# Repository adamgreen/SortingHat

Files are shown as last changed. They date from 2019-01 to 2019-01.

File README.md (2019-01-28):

# BLE Harry Potter Sorting Hat
This project replaces the original electronics in a [Harry Potter Sorting Hat](https://www.barnesandnoble.com/w/home-gift-harry-potter-sorting-hat/30008992) with a Nordic nRF5 BLE capable device.

## Legal Notes
* This Harry Potter Sorting Hat upgrade is created by a Harry Potter fan for other such fans. It is not sponsored or endorsed by Warner Bros. Entertainment or J.K. Rowling.
* Materials from the Harry Potter series of films are the intellectual property of Warner Bros. Entertainment.

## Project Overview
The user can connect to the device with a BLE capable phone using the Nordic UART service and send **g**, **r**, **h**, or **s** to select the house and then a series of random clips from the movies will play, ending with an announcement of the selected house.

The sound clips are stored on SD card as .wav files and are played back by pulsing a pin as a 1-bit DAC at 22.05kHz. The mouth is connected to a hobby servo instead of the original open-loop DC motor and the position of this servo is based on the volume in upcoming audio buffers.

## Credits
The sound clips and the code flow to randomly select between them originates from the https://github.com/gowenrw/arduino_sorting_hat repository created by [@gowenrw](https://github.com/gowenrw).

This sample is heavily influenced by Nordic's BLE UART Service (ble_app_uart) SDK sample.

## Firmware Build
I have only tested the build on macOS but it might work on other Posix operating systems too.

**Note:** Building the firmware and deploying it to the nRF51 requires the **nrfjprog** tool. The archive for your OS can be downloaded from [here](https://www.nordicsemi.com/Software-and-Tools/Development-Tools/nRF5-Command-Line-Tools). You will also need a SEGGER J-Link JTAG/SWD Debugger. If your projects are of a non-commercial nature, you can use this [low cost module available from Adafruit](https://www.adafruit.com/product/3571).

* `make sdk` will download and install the required Nordic SDK. This should only need to be done once.
* `make audio` will generate the .wav files to be placed in the root folder of the SD card.
* `make flash_softdevice` will install the required Nordic SoftDevice on the nRF51422 microcontroller using the J-Link debugger. This will typically only need to be done once for each microcontroller.
* `make all` will build the hat firmware.
* `make flash` will build the hat firmware and deploy it using the J-Link debugger.

# Bill of Materials
Description | Quantity | Part Number(s)
------------|----------|---------------
[LM386MMX-1 Low Voltage Audio Amplifier](https://www.digikey.com/products/en?keywords=LM386MMX-1/NOPBCT-ND) | 1 | IC1
[MIC5205 Linear Regulator - 3.3V 150mA SOT23-5](https://www.digikey.com/products/en?keywords=576-1259-1-ND) | 1 | U1
[microSD Socket](https://www.sparkfun.com/products/127) | 1 | JP1
[Dynastream N5150M5CD - nRF51422 Module](https://www.digikey.com/products/en?keywords=N5150M5CD) | 1 | U2
[0.01uF Capacitor - 0805](https://www.adafruit.com/product/441) | 1 | C5
[0.1uF Capacitor - 0805](https://www.adafruit.com/product/441) | 4 | C3, C4, C8, C10
[10uF Capacitor (16V) - Tantalum](https://www.digikey.com/products/en?keywords=478-8235-1-ND) | 4 | C1, C2, C6, C7
[220uF Capacitor (10V) - Tantalum](https://www.digikey.com/products/en?keywords=478-6612-1-ND) | 1 | C9
[10kΩ Resistor - 0805](https://www.adafruit.com/product/441) | 1 | R1
[10Ω Resistor - 0805](https://www.adafruit.com/product/441) | 1 | R6
[1kΩ Resistor - 0805](https://www.adafruit.com/product/441) | 3 | R2, R3, R7
[4.7kΩ Resistor - 0805](https://www.adafruit.com/product/441) | 1 | R4
[10kΩ 11-TurnTrimmer Potentiometer](https://www.digikey.com/products/en?keywords=3223W-1-103ECT-ND) | 1 | R5
[Sliding Switch](https://www.digikey.com/products/en?keywords=EG2481-ND) | 1 | S1

# Schematic
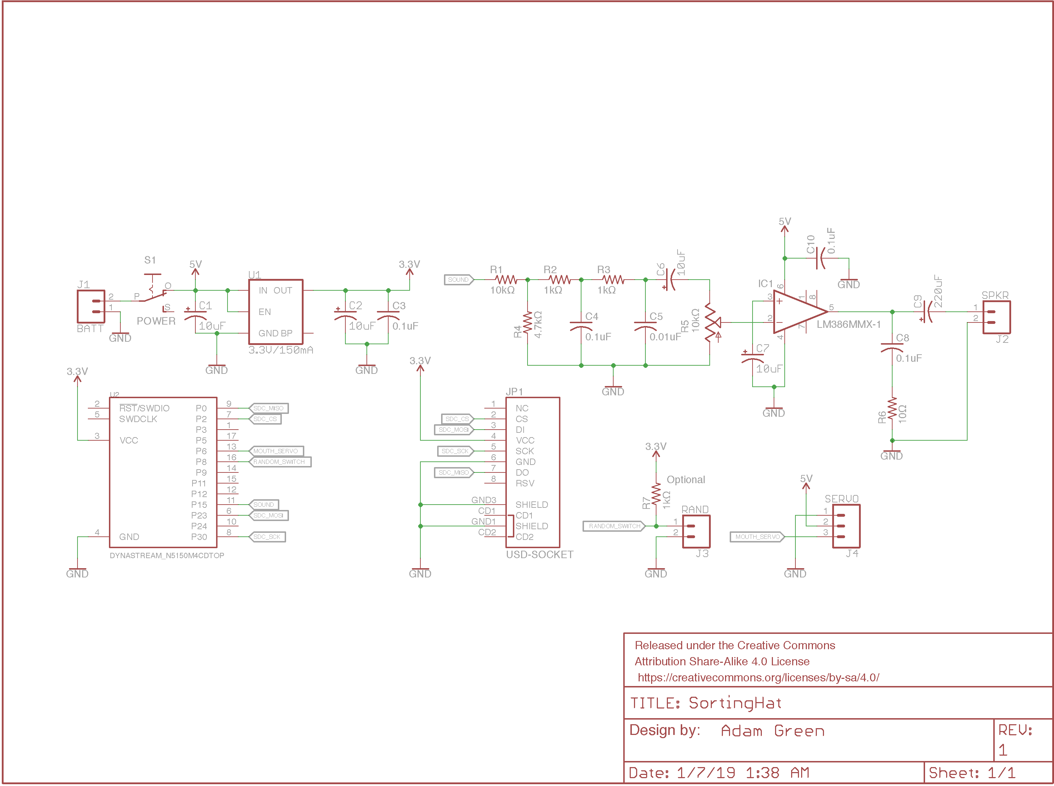
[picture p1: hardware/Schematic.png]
Schematic


# OSHPark Renderings of PCB
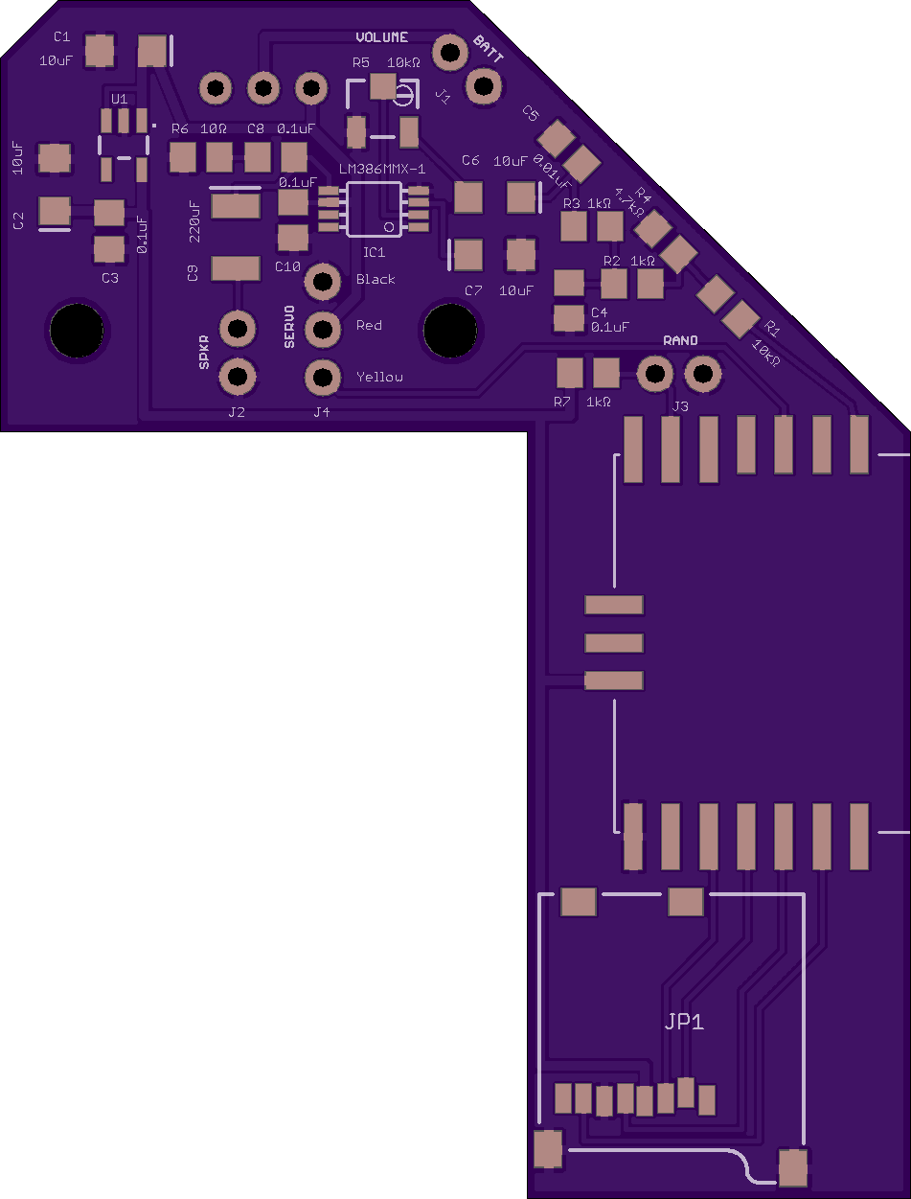
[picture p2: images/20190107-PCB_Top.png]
OSHPark rendering of PCB Top

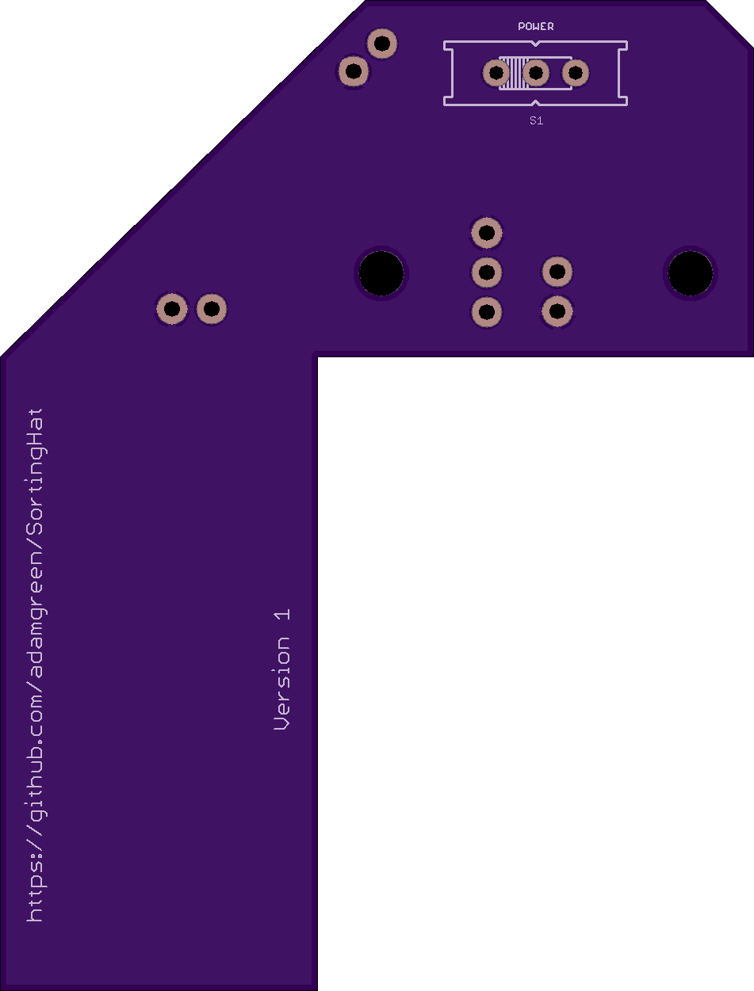
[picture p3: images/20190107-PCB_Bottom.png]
OSHPark rendering of PCB Bottom


# Postmortem
Things that worked well in the current prototype version of this sorting hat as documented here:
* Getting the house selection via BLE from a custom iOS application.
* Changing out the reciprocating mouth mechanism to instead use a servo with a push-rod mechanism. 
* Reading in the .wav files from uSD card.
* Continuing to support the original button on the hat brim for random house selection.

Things that didn't work as well as I had hoped:
* The LM386 as seen in the above schematic was very sensitive to noise in the 5V supply caused by the servo so I ended up removing it and just using a NPN BJT as described [here](https://makezine.com/projects/make-35/advanced-arduino-sound-synthesis/).
* The audio quality was quite low. There was a hum in the audio. Seems like it might have been from noise on the nRF51 sound output pin when it is in the high state.
* While the LM386 volume level was Ok, once I switched it out for a single NPN transistor, the volume level was quite low.
* The PCB should be modified to better fit inside the hat:
  * It is currently too wide at the bottom, to the right of the uSD card reader and I had to file it down. I should have cut the bottom in like the top and put the SD card reader there pointed inwards (to the left). 
  * The power connector is hard to get to since it is right underneath the speaker.
  * I forgot to label the pins for the BATT header.
  * The antenna of the nRF51 module is a bit tight against the side of the hat. Could have narrowed the PCB width down a bit and pulled module to the left a mm or so.
  * The R5 potentiometer was way too close to back edge and actually got bent up by speaker holder.
  * The C1 capacitor should be moved down a bit as it currently hits up against the bottom of the speaker holder.
  
Things I would change if I ever come back to this project to build a newer prototype version:
* Update the PCB to fix the issues mentioned above.
* Switch to using a nRF52 based microcontroller instead. This chip supports DMA based PWM and I2S.
* Use a I2S based amplified DAC such as the [MAX98357A](https://www.adafruit.com/product/3006) to replace the 1-bit DAC and LM386 in the current project. This would probably allow the BLE connection to be maintained while the house announcement was in progress and greatly improve the sound quality.

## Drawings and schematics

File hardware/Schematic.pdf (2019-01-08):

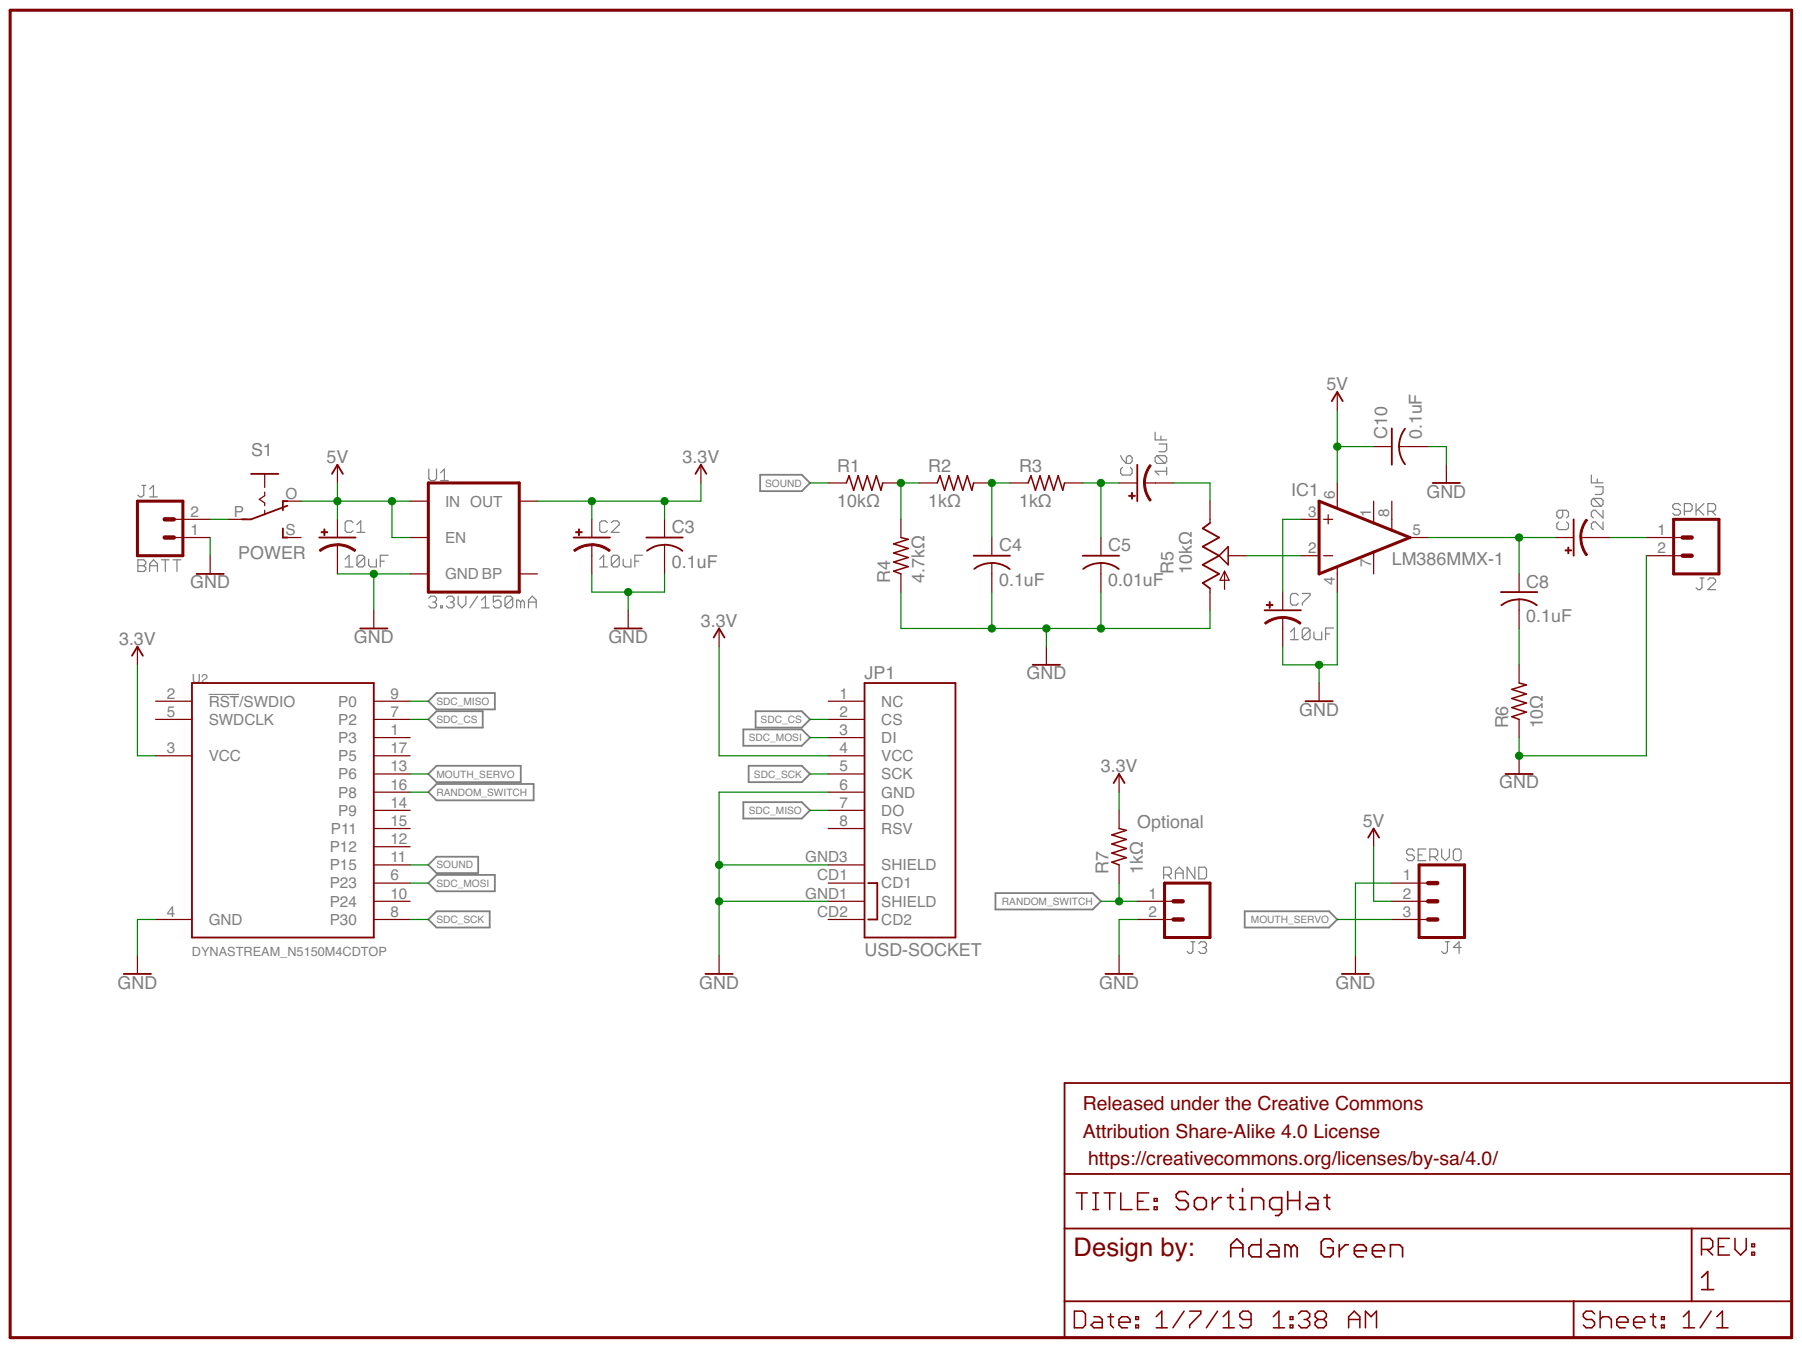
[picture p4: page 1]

Released under the Creative Commons Attribution Share-Alike 4.0 License

https://creativecommons.org/licenses/by-sa/4.0/

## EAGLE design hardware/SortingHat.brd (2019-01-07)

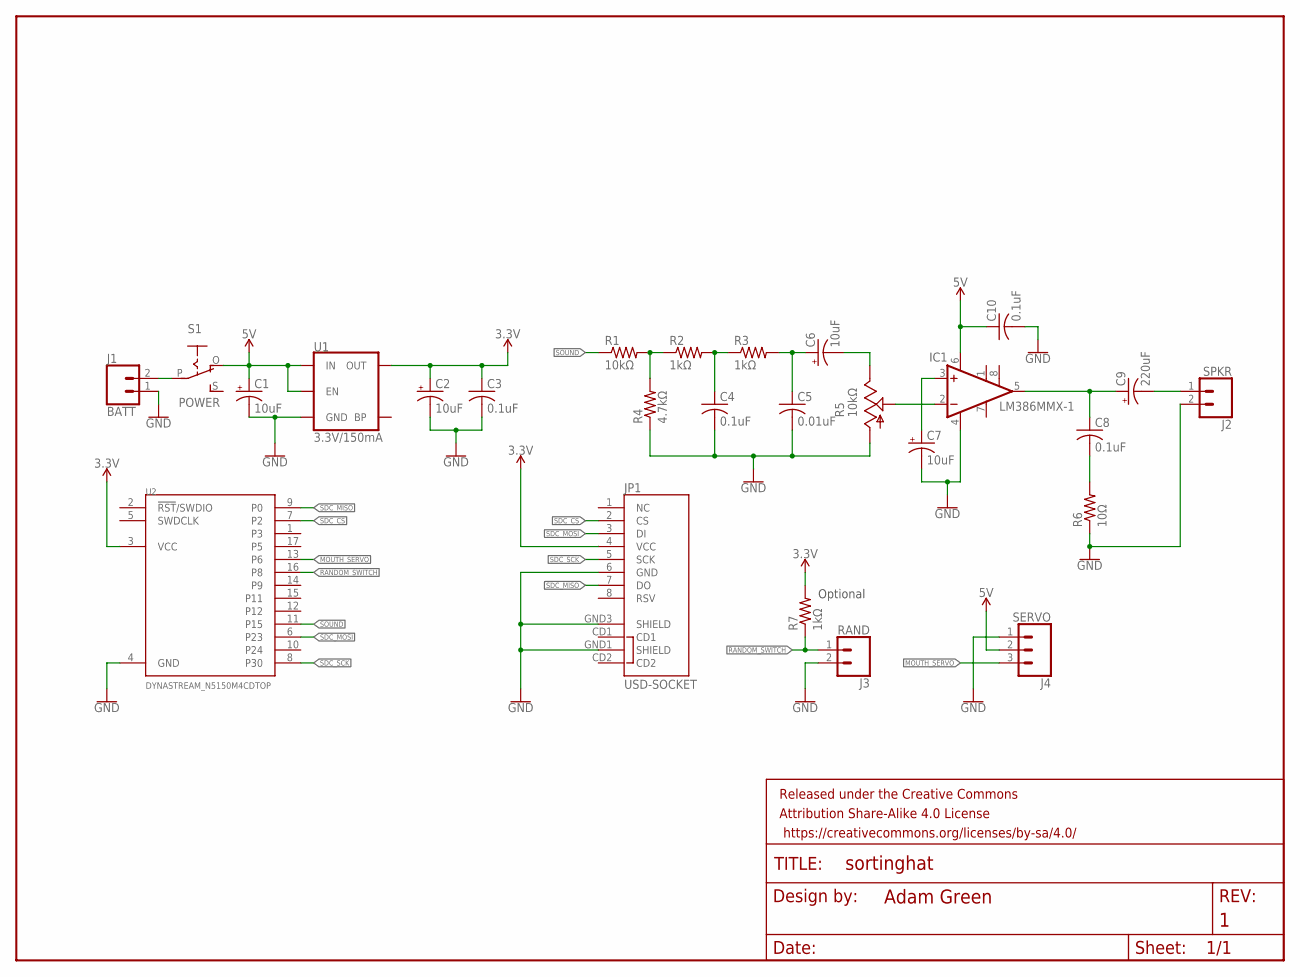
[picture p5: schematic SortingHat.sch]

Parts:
C1, C2, C6, C7: 10uF; EIA3216
C3, C4, C8, C10: 0.1uF; C0805
C5: 0.01uF; C0805
C9: 220uF; EIA3528
FRAME1: FRAME-LETTER; CREATIVE_COMMONS
IC1: LM386MMX-1; MMSOP08
J1: BATT; 1X02_NO_SILK
J2: SPKR; 1X02_NO_SILK
J3: RAND; 1X02_NO_SILK
J4: SERVO; 1X03_NO_SILK
JP1: USD-SOCKET; MICROSD_1:1
R1: 10kΩ; R0805
R2, R3, R7: 1kΩ; R0805
R4: 4.7kΩ; R0805
R5: 10kΩ; 3223W
R6: 10Ω; R0805
S1: POWER; EG1218
U1: 3.3V/150mA; SOT23-5
U2: DYNASTREAM_N5150M4CDTOP; N5150M4CD_TOP

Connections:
3.3V: C2.+, C3.1, JP1.4 (VCC), R7.2, U1.5 (OUT), U2.3 (VCC)
5V: C1.+, C10.1, IC1.6 (VS), J4.2, S1.O, U1.1 (IN), U1.3 (EN)
GND: C1.-, C2.-, C3.2, C4.2, C5.2, C7.-, C10.2, IC1.4 (GND), J1.1, J2.2, J3.2, J4.1, JP1.6 (GND), JP1.GND1 (SHIELD), JP1.GND3 (SHIELD), R4.1, R5.1 (A), R6.1, U1.2 (GND), U2.4 (GND)
MOUTH_SERVO: J4.3, U2.13 (P6)
unnamed: J1.2, S1.P
unnamed: R1.2, R2.1, R4.2
unnamed: C4.1, R2.2, R3.1
unnamed: C5.1, C6.+, R3.2
unnamed: C6.-, R5.3 (E)
unnamed: C9.C (-), J2.1
unnamed: IC1.2 (-IN), R5.2 (S)
unnamed: C7.+, IC1.3 (+IN)
unnamed: C8.1, C9.A (+), IC1.5 (OUT)
unnamed: C8.2, R6.2
RANDOM_SWITCH: J3.1, R7.1, U2.16 (P8)
SDC_CS: JP1.2 (CS), U2.7 (P2)
SDC_MISO: JP1.7 (DO), U2.9 (P0)
SDC_MOSI: JP1.3 (DI), U2.6 (P23)
SDC_SCK: JP1.5 (SCK), U2.8 (P30)
SOUND: R1.1, U2.11 (P15)

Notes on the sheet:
Optional

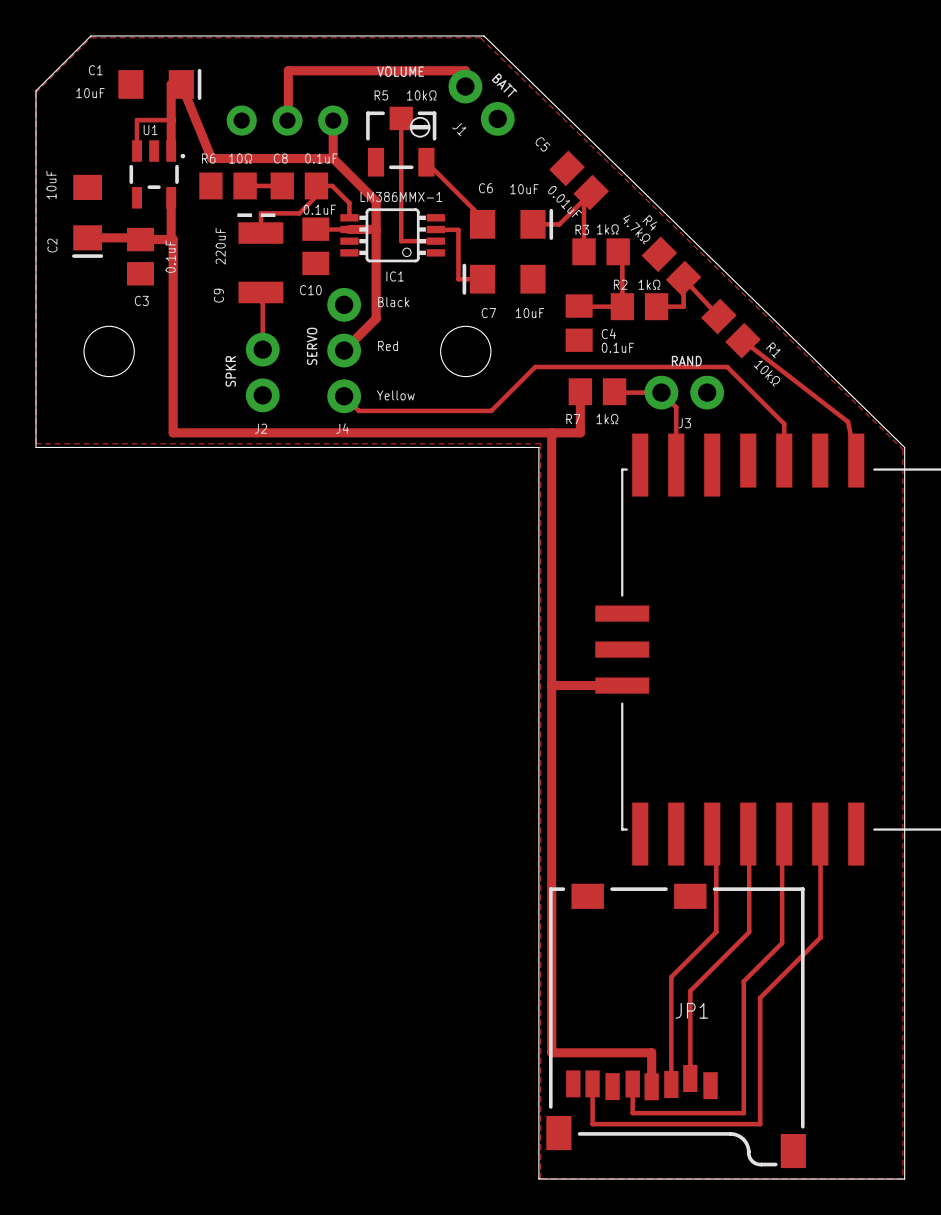
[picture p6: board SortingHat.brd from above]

Board: 2 copper layers, 48.3 x 63.5 mm, 27 parts (1 on the bottom side), 20 nets.

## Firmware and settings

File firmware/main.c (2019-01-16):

/*  Copyright (C) 2019  Adam Green (https://github.com/adamgreen)

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
    This program is distributed in the hope that it will be useful,
    but WITHOUT ANY WARRANTY; without even the implied warranty of
    MERCHANTABILITY or FITNESS FOR A PARTICULAR PURPOSE.  See the
    GNU General Public License for more details.
*/
/* A Bluetooth Low Energy (BLE) enabled Harry Potter Sorting Hat

   This project replaces the original electronics in the Harry Potter Sorting Hat from Barnes and Noble,
   https://www.barnesandnoble.com/w/home-gift-harry-potter-sorting-hat/30008992, with a Nordic nRF5 BLE capable device.

   Pins.h contains the definitions for which pins are connected to which external hardware.

   The user can connect to the device with a BLE capable phone using the Nordic UART service and send 'g', 'r', 'h', or
   's' to select the house and then a series of random clips from the movies will play, ending with an announcement of
   the selected house.

   The sound clips are stored on SD card as .wav files and are played back by pulsing a pin as a 1-bit DAC at 22.05kHz.
   The mouth is connected to a hobby servo instead of the original open-loop DC motor and the position of this servo
   is based on the volume in upcoming audio buffers.

   The sound clips and the code flow to randomly select between them originates from
   https://github.com/gowenrw/arduino_sorting_hat created by @gowenrw, Richard Gowen.

   This sample is heavily influenced by Nordic's BLE UART Service (ble_app_uart) SDK sample.
*/
#include <ctype.h>
#include <math.h>
#include <stdint.h>
#include <string.h>
#include <app_button.h>
#include <app_pwm.h>
#include <app_timer.h>
#include <app_uart.h>
#include <ble_advdata.h>
#include <ble_advertising.h>
#include <ble_conn_params.h>
#include <ble_hci.h>
#include <ble_nus.h>
#include <nordic_common.h>
#include <nrf.h>
#include <nrf_drv_gpiote.h>
#include <nrf_drv_rng.h>
#include <softdevice_handler.h>
#include "WaveFile.h"
#include "OneBitSound.h"
#include "Pins.h"



// The service database for this device can't be changed at runtime. Must be non-zero for DFU.
#define IS_SRVC_CHANGED_CHARACT_PRESENT 0

#if (NRF_SD_BLE_API_VERSION == 3)
// MTU size used in the softdevice enabling and to reply to a BLE_GATTS_EVT_EXCHANGE_MTU_REQUEST event.
#define NRF_BLE_MAX_MTU_SIZE            GATT_MTU_SIZE_DEFAULT
#endif

// Reply when unsupported features are requested.
#define APP_FEATURE_NOT_SUPPORTED       BLE_GATT_STATUS_ATTERR_APP_BEGIN + 2

// This application doesn't need to act as a central device.
#define CENTRAL_LINK_COUNT              0
// This application is a peripheral and only hosts 1 peripheral link back to a central device.
#define PERIPHERAL_LINK_COUNT           1

#define DEVICE_NAME                     "SortingHat"

// UUID type for the Nordic UART Service (vendor specific).
#define NUS_SERVICE_UUID_TYPE           BLE_UUID_TYPE_VENDOR_BEGIN

// The advertising interval (in units of 0.625 ms. This value corresponds to 40 ms).
#define APP_ADV_INTERVAL                64
// The advertising timeout (in units of seconds).
#define APP_ADV_TIMEOUT_IN_SECONDS      180

// Value of the RTC1 PRESCALER register.
#define APP_TIMER_PRESCALER             0
// Size of timer operation queues.
#define APP_TIMER_OP_QUEUE_SIZE         4

// Timings for how often peripheral and central should communicate over the link. The shorter the interval, the more
// data that can be sent over the link but uses more CPU and power resources.
// Minimum acceptable connection interval (20 ms), Connection interval uses 1.25 ms units.
#define MIN_CONN_INTERVAL               MSEC_TO_UNITS(20, UNIT_1_25_MS)
// Maximum acceptable connection interval (75 ms), Connection interval uses 1.25 ms units.
#define MAX_CONN_INTERVAL               MSEC_TO_UNITS(75, UNIT_1_25_MS)
// The number of the connection interval events that the peripheral can ignore before response is required.
#define SLAVE_LATENCY                   0

// Connection supervisory timeout (4 seconds), Supervision Timeout uses 10 ms units.
#define CONN_SUP_TIMEOUT                MSEC_TO_UNITS(4000, UNIT_10_MS)
// Time from initiating event (connect or start of notification) to first time sd_ble_gap_conn_param_update is called (5 seconds).
#define FIRST_CONN_PARAMS_UPDATE_DELAY  APP_TIMER_TICKS(5000, APP_TIMER_PRESCALER)
// Time between each call to sd_ble_gap_conn_param_update after the first call (30 seconds).
#define NEXT_CONN_PARAMS_UPDATE_DELAY   APP_TIMER_TICKS(30000, APP_TIMER_PRESCALER)
// Number of attempts before giving up the connection parameter negotiation.
#define MAX_CONN_PARAMS_UPDATE_COUNT    3

#define UART_TX_BUF_SIZE                256
#define UART_RX_BUF_SIZE                256



static ble_nus_t                    g_nordicUartService;
static uint16_t                     g_currBleConnection = BLE_CONN_HANDLE_INVALID;

// UUIDS returned in advertising scan response.
static ble_uuid_t                   g_advertiseUuids[] = {{BLE_UUID_NUS_SERVICE, NUS_SERVICE_UUID_TYPE}};

// Where the main thread should write the next entry in OneBitSound's g_soundBuffers array.
static          size_t              g_soundBufferWrite = 0;

// The number of buffers that have been filled with descending values to ramp down the voltage to the amplifier input.
static          uint32_t            g_soundFinalBuffers = 0;

// The list of wave files to play.
static          const char*         g_wavesToPlay[6];
static          const char**        g_ppCurrentWave = &g_wavesToPlay[5];

// The .wav file handle currently being read for playback.
static          FIL                 g_wavFile;

// PWM instance for servo control uses TIMER2.
APP_PWM_INSTANCE(PWM1, 2);

// The number of clock ticks for mouth fully open and closed position of servo.
static          int32_t             g_closedMouthClockTicks;
static          int32_t             g_openMouthClickTicks;
static          int32_t             g_mouthClockTickRange;



// Forward Function Declarations.
static void pullSoundAndServoOutputPinsLow();
static void initUart(void);
static void uartEventHandler(app_uart_evt_t* pEvent);
static void playHouseAnnouncement(uint8_t houseSelection);
static void soundBufferRead(void* pEventData, uint16_t eventSize);
static void  fillFinalSoundBuffers();
static int32_t calculateMaxVolume(uint8_t* pData, size_t length);
static void enterLowPowerModeUntilNextScheduledEvent();
static void waitForBleHouseChoice();
static void initRandomSwitch();
static void randomSelectionSwitchPressedHandler(nrf_drv_gpiote_pin_t pin, nrf_gpiote_polarity_t action);
static void initBleStack(void);
static void bleEventHandler(ble_evt_t* pBleEvent);
static void handleBleEventsForApplication(ble_evt_t* pBleEvent);
static void initGapParams(void);
static void initBleUartService(void);
static void nordicUartServiceHandler(ble_nus_t* pNordicUartService, uint8_t* pData, uint16_t length);
static void initBleAdvertising(void);
static void bleAdvertisingEventHandler(ble_adv_evt_t bleAdvertisingEvent);
static void enterDeepSleep(void);
static void initConnectionParameters(void);
static void connectionParameterEventHandler(ble_conn_params_evt_t* pEvent);
static void connectionParameterErrorHandler(uint32_t errorCode);
static void enterLowPowerModeUntilNextEvent(void);



int main(void)
{
    pullSoundAndServoOutputPinsLow();

    initUart();
    printf("\nHarry Potter Sorting Hat Hack!\n");

    // If the user selected a house via a BLE connection, the selection will have been placed in GPREGRET and then the
    // device reset.
    uint8_t houseSelection = NRF_POWER->GPREGRET;
    NRF_POWER->GPREGRET = 0;
    if (houseSelection != 0)
    {
        playHouseAnnouncement(houseSelection);
    }
    else
    {
        waitForBleHouseChoice();
    }

    return -1;
}

static void pullSoundAndServoOutputPinsLow()
{
    nrf_gpio_cfg_output(SOUND_PIN);
    nrf_gpio_pin_clear(SOUND_PIN);
    nrf_gpio_cfg_output(MOUTH_SERVO_PIN);
    nrf_gpio_pin_clear(MOUTH_SERVO_PIN);
}

static void initUart(void)
{
    uint32_t                     errorCode;
    const app_uart_comm_params_t commParams =
    {
        UART_RX_PIN,
        UART_TX_PIN,
        0xFF, // RTS not used
        0xFF, // CTS not used
        APP_UART_FLOW_CONTROL_DISABLED,
        false,
        UART_BAUDRATE_BAUDRATE_Baud115200
    };

    APP_UART_FIFO_INIT(&commParams,
                       UART_RX_BUF_SIZE,
                       UART_TX_BUF_SIZE,
                       uartEventHandler,
                       APP_IRQ_PRIORITY_LOWEST,
                       errorCode);
    APP_ERROR_CHECK(errorCode);
}

static void uartEventHandler(app_uart_evt_t * pEvent)
{
    uint8_t     dummyByte;

    switch (pEvent->evt_type)
    {
        case APP_UART_DATA_READY:
            // Just eat and discard any received UART bytes at this time.
            app_uart_get(&dummyByte);
            break;

        case APP_UART_COMMUNICATION_ERROR:
            APP_ERROR_HANDLER(pEvent->data.error_communication);
            break;

        case APP_UART_FIFO_ERROR:
            APP_ERROR_HANDLER(pEvent->data.error_code);
            break;

        default:
            break;
    }
}

// The sound clips and the code flow to randomly select between them originates from
// https://github.com/gowenrw/arduino_sorting_hat created by Richard Gowen (@alt_bier)
static void playHouseAnnouncement(uint8_t houseSelection)
{
    uint32_t errorCode;

    printf("Playing house announcement...\n");

    APP_SCHED_INIT(0, 2);

    // Initialize the PWM instance used for the servo control of the hat's mouth.
    app_pwm_config_t pwm1_cfg = APP_PWM_DEFAULT_CONFIG_1CH(1000000/50, MOUTH_SERVO_PIN);
    pwm1_cfg.pin_polarity[0] = APP_PWM_POLARITY_ACTIVE_HIGH;

    // Initialize and enable PWM for the servo.
    errorCode = app_pwm_init(&PWM1, &pwm1_cfg, NULL);
    APP_ERROR_CHECK(errorCode);
    app_pwm_enable(&PWM1);

    // Determine the number of clock ticks for mouth fully closed and mouth fully opened.
    float ticksPerMillisecond = (float)app_pwm_cycle_ticks_get(&PWM1) / 20.0f;
    g_closedMouthClockTicks = ticksPerMillisecond * 1.75f;
    g_mouthClockTickRange = ticksPerMillisecond * -0.4f;
    g_openMouthClickTicks = g_closedMouthClockTicks + g_mouthClockTickRange;
    // Amplify the mouth movement a bit.
    g_mouthClockTickRange *= 1.5;

    fatfsInit();

    const char* pHouseClip;
    switch (houseSelection)
    {
    case 'g':
        pHouseClip = "h-gryff1.wav";
        break;
    case 'r':
        pHouseClip = "h-raven1.wav";
        break;
    case 'h':
        pHouseClip = "h-huffl1.wav";
        break;
    case 's':
        pHouseClip = "h-slyth1.wav";
        break;
    default:
        return;
    }

    // Setup Audio File Name Arrays
    // Array of Stalling Audio Clips
    static const char* stallingClips[] =
    {
        "s-ahrigh.wav", // "Ahh... Right then."
        "s-diffic.wav", // "Hmm... Difficult, very difficult."
        "s-itsall.wav", // "You could be great, you know.  It's all here, in your head." -- break into two clips put great to attributes
        "s-ohyes1.wav", // "Oh, Yes."
        "s-righto.wav", // "Hm, right. Ok."
        "s-wheret.wav"  // "But where to put you?"
    };
    // Array of Attribute Audio Clips
    static const char* attributeClips[] =
    {
        "t-courag.wav", // "Plenty of courage, I see."
        "t-notaba.wav", // "Not a bad mind a..." -- needs work, either clip or expand or replace with great clip above
        "t-readym.wav", // "Ahhh yes. A ready mind."
        "t-talent.wav"  // "There's talent."
    };
    // Array of Audio Clips to play just before announcing house.
    static const char* penultimateClips[] =
    {
        "k-better.wav", // "Better be..."
        "k-iknow1.wav", // "I Know!"
        "k-iknowj.wav", // "I know just what to do with you."
        "k-youbel.wav"  // "You belong in..."
    };

    // Using the hardware random number generator since it exists and hard to get unique random selections across
    // CPU resets otherwise.
    uint8_t randNumbers[4];
    uint8_t availableBytes = 0;
    errorCode = nrf_drv_rng_init(NULL);
    APP_ERROR_CHECK(errorCode);
    do
    {
        nrf_drv_rng_bytes_available(&availableBytes);
    } while (availableBytes < sizeof(randNumbers));
    errorCode = nrf_drv_rng_rand(randNumbers, sizeof(randNumbers));
    APP_ERROR_CHECK(errorCode);

    // Determine random audio clip numbers to be played.
    int stallClip1 = randNumbers[0] % ARRAY_SIZE(stallingClips);
    int stallClip2 = (stallClip1 + 1 + (randNumbers[1] % (ARRAY_SIZE(stallingClips)-1))) % ARRAY_SIZE(stallingClips);
    int attributeClip = randNumbers[2] % ARRAY_SIZE(attributeClips);
    int penultimateClip = randNumbers[3] % ARRAY_SIZE(penultimateClips);

    // UNDONE: Remove in final version.
    if (stallClip1 == stallClip2)
    {
        // If my math above is correct then stall clip #1 should never be the same as stall clip #2.
        { __asm volatile ("bkpt #0"); }
    }

    // Queue them up for playback.
    g_wavesToPlay[0] = stallingClips[stallClip1];
    g_wavesToPlay[1] = attributeClips[attributeClip];
    g_wavesToPlay[2] = stallingClips[stallClip2];
    g_wavesToPlay[3] = penultimateClips[penultimateClip];
    g_wavesToPlay[4] = pHouseClip;
    g_wavesToPlay[5] = NULL;
    g_ppCurrentWave = &g_wavesToPlay[0];

    // Call soundBufferRead() synchronously to pre-fill the sound buffers with samples from the .wav files before
    // calling soundInit() to start the audio playback process.
    emptySoundBuffers();
    soundBufferRead(NULL, 0);

    // Start the timer interrupt used for audio playback.
    errorCode = soundInit(SOUND_PIN, soundBufferRead);
    APP_ERROR_CHECK(errorCode);

    for (;;)
    {
        enterLowPowerModeUntilNextScheduledEvent();
    }
}

// Fills in sound buffers with samples from the list of SD card based .wav audio files.
static void soundBufferRead(void * pEventData, uint16_t eventSize)
{
    if (*g_ppCurrentWave == NULL)
    {
        fillFinalSoundBuffers();
        return;
    }
    if (g_wavFile.obj.fs != 0 && f_eof(&g_wavFile))
    {
        f_close(&g_wavFile);
        g_ppCurrentWave++;
    }

    // Using a while to skip over any files that fail to open.
    while (*g_ppCurrentWave && g_wavFile.obj.fs == 0)
    {
        FRESULT result = openWavFile(*g_ppCurrentWave, &g_wavFile);
        if (result != FR_OK)
        {
            f_close(&g_wavFile);
            g_ppCurrentWave++;
        }
    }
    if (g_wavFile.obj.fs == 0)
    {
        fillFinalSoundBuffers();
        return;
    }

    // Fill in as many of the buffer as possible.
    for (size_t i = 0 ; i < ARRAY_SIZE(g_soundBuffers) ; i++)
    {
        SoundBuffer* pBuffer = &g_soundBuffers[g_soundBufferWrite];
        if (pBuffer->index < SOUND_BUFFER_SIZE)
        {
            // This buffer isn't empty.
            break;
        }

        UINT bytesRead;
        FRESULT result = f_read(&g_wavFile, (void*)pBuffer->data, sizeof(pBuffer->data), &bytesRead);
        if (result != FR_OK)
        {
            fillFinalSoundBuffers();
            return;
        }
        if (bytesRead < sizeof(pBuffer->data))
        {
            memset((void*)&pBuffer->data[bytesRead], 0x80, sizeof(pBuffer->data) - bytesRead);
        }
        pBuffer->index = 0;
        g_soundBufferWrite = (g_soundBufferWrite + 1) % ARRAY_SIZE(g_soundBuffers);

        // Set mouth position based on maximum volume of samples in this buffer.
        // Setting the position early when reading the samples should be ok since it gives servo time to move mouth
        // into position.
        uint16_t servoPos = g_closedMouthClockTicks +
                            (calculateMaxVolume((uint8_t*)pBuffer->data, sizeof(pBuffer->data)) *
                             g_mouthClockTickRange / 128);
        if (servoPos < g_openMouthClickTicks)
        {
            // Don't let the mouth attempt to open too far.
            servoPos = g_openMouthClickTicks;
        }
        app_pwm_channel_duty_ticks_set(&PWM1, 0, servoPos);
    }
}

// The purpose of this function is really two-fold:
// * Fill in the last 1/2 second or so of audio with decreasing values to slowly ramp down the analog audio output
//   to 0 volts.
// * After ramping down the voltage, the CPU will be reset to go back into BLE mode so that the user can pick
//   another house for the next iteration.
static void fillFinalSoundBuffers()
{
    if (g_soundFinalBuffers > 22)
    {
        // Can reset the device once a full set of ramping down final buffers has been played
        // to relax the speaker coil gently.
        NVIC_SystemReset();
        return;
    }
    else
    {
        // Ramp the analog sound output down from midpoint to 0V.
        SoundBuffer* pBuffer = &g_soundBuffers[g_soundBufferWrite];
        uint8_t value = 0x80 - 6 * g_soundFinalBuffers;
        if (value > 0x80)
        {
            value = 0;
        }
        memset((void*)pBuffer->data, value, sizeof(pBuffer->data));
        pBuffer->index = 0;
        g_soundBufferWrite = (g_soundBufferWrite + 1) % ARRAY_SIZE(g_soundBuffers);
    }
    g_soundFinalBuffers++;
    app_pwm_channel_duty_ticks_set(&PWM1, 0, g_closedMouthClockTicks);
}

static int32_t calculateMaxVolume(uint8_t* pData, size_t length)
{
    int32_t max = 0;
    while (length-- > 0)
    {
        uint8_t data = *pData++;

        int32_t diff;
        if (data > 0x80)
        {
            diff = data - 0x80;
        }
        else
        {
            diff = 0x80 - data;
        }

        if (diff > max)
        {
            max = diff;
        }
    }
    return max;
}

static void enterLowPowerModeUntilNextScheduledEvent()
{
    __WFE();
    app_sched_execute();
}

static void waitForBleHouseChoice()
{
    printf("Waiting for house selection over BLE connection...\n");

    // Initialize.
    APP_TIMER_INIT(APP_TIMER_PRESCALER, APP_TIMER_OP_QUEUE_SIZE, false);

    initRandomSwitch();
    initBleStack();
    initGapParams();
    initBleUartService();
    initBleAdvertising();
    initConnectionParameters();

    uint32_t errorCode = ble_advertising_start(BLE_ADV_MODE_FAST);
    APP_ERROR_CHECK(errorCode);

    for (;;)
    {
        enterLowPowerModeUntilNextEvent();
    }
}

static void initRandomSwitch()
{
    // Configure to interrupt if the switch for random house selection is pressed.
    nrf_drv_gpiote_in_config_t config =
    {
        .is_watcher = false,
        .hi_accuracy = false,
        .pull = NRF_GPIO_PIN_PULLUP,
        .sense = NRF_GPIOTE_POLARITY_HITOLO
    };
    uint32_t errorCode = nrf_drv_gpiote_init();
    APP_ERROR_CHECK(errorCode);
    errorCode = nrf_drv_gpiote_in_init(RANDOM_SWITCH_PIN, &config, randomSelectionSwitchPressedHandler);
    APP_ERROR_CHECK(errorCode);
    nrf_drv_gpiote_in_event_enable(RANDOM_SWITCH_PIN, true);
}

static void randomSelectionSwitchPressedHandler(nrf_drv_gpiote_pin_t pin, nrf_gpiote_polarity_t action)
{
    // Using the hardware random number generator to pick a house.
    uint8_t randNumber;
    uint8_t availableBytes = 0;
    uint32_t errorCode = nrf_drv_rng_init(NULL);
    APP_ERROR_CHECK(errorCode);
    do
    {
        nrf_drv_rng_bytes_available(&availableBytes);
    } while (availableBytes < sizeof(randNumber));
    errorCode = nrf_drv_rng_rand(&randNumber, sizeof(randNumber));
    APP_ERROR_CHECK(errorCode);

    // Randomly select the house for the announcement.
    static uint8_t houses[4] = { 'g', 'r', 'h', 's' };
    uint8_t house = houses[randNumber % ARRAY_SIZE(houses)];

    // Remember the selected house before resetting the CPU.
    NRF_POWER->GPREGRET = house;
    NVIC_SystemReset();
}

static void initBleStack(void)
{
    uint32_t errorCode;

    nrf_clock_lf_cfg_t clockConfig = NRF_CLOCK_LFCLKSRC;

    // Initialize SoftDevice.
    SOFTDEVICE_HANDLER_INIT(&clockConfig, NULL);

    ble_enable_params_t defaultBleParams;
    errorCode = softdevice_enable_get_default_config(CENTRAL_LINK_COUNT,
                                                    PERIPHERAL_LINK_COUNT,
                                                    &defaultBleParams);
    APP_ERROR_CHECK(errorCode);

    //Check the ram settings against the used number of links
    CHECK_RAM_START_ADDR(CENTRAL_LINK_COUNT,PERIPHERAL_LINK_COUNT);

    // Enable BLE stack.
#if (NRF_SD_BLE_API_VERSION == 3)
    defaultBleParams.gatt_enable_params.att_mtu = NRF_BLE_MAX_MTU_SIZE;
#endif
    errorCode = softdevice_enable(&defaultBleParams);
    APP_ERROR_CHECK(errorCode);

    // Subscribe for BLE events.
    errorCode = softdevice_ble_evt_handler_set(bleEventHandler);
    APP_ERROR_CHECK(errorCode);
}

static void bleEventHandler(ble_evt_t * pBleEvent)
{
    ble_conn_params_on_ble_evt(pBleEvent);
    ble_nus_on_ble_evt(&g_nordicUartService, pBleEvent);
    handleBleEventsForApplication(pBleEvent);
    ble_advertising_on_ble_evt(pBleEvent);
}
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

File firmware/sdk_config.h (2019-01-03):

#ifndef SDK_CONFIG_H
#define SDK_CONFIG_H
// <<< Use Configuration Wizard in Context Menu >>>\n
#ifdef USE_APP_CONFIG
#include "app_config.h"
#endif
// <h> nRF_BLE

//==========================================================
// <q> BLE_ADVERTISING_ENABLED  - ble_advertising - Advertising module


#ifndef BLE_ADVERTISING_ENABLED
#define BLE_ADVERTISING_ENABLED 1
#endif

// <q> BLE_DTM_ENABLED  - ble_dtm - Module for testing RF/PHY using DTM commands


#ifndef BLE_DTM_ENABLED
#define BLE_DTM_ENABLED 0
#endif

// <q> BLE_RACP_ENABLED  - ble_racp - Record Access Control Point library


#ifndef BLE_RACP_ENABLED
#define BLE_RACP_ENABLED 0
#endif

// <q> NRF_BLE_QWR_ENABLED  - nrf_ble_qwr - Queued writes support module (prepare/execute write)


#ifndef NRF_BLE_QWR_ENABLED
#define NRF_BLE_QWR_ENABLED 0
#endif

// <q> PEER_MANAGER_ENABLED  - peer_manager - Peer Manager


#ifndef PEER_MANAGER_ENABLED
#define PEER_MANAGER_ENABLED 0
#endif

// </h>
//==========================================================

// <h> nRF_BLE_Services

//==========================================================
// <q> BLE_ANCS_C_ENABLED  - ble_ancs_c - Apple Notification Service Client


#ifndef BLE_ANCS_C_ENABLED
#define BLE_ANCS_C_ENABLED 0
#endif

// <q> BLE_ANS_C_ENABLED  - ble_ans_c - Alert Notification Service Client


#ifndef BLE_ANS_C_ENABLED
#define BLE_ANS_C_ENABLED 0
#endif

// <q> BLE_BAS_C_ENABLED  - ble_bas_c - Battery Service Client


#ifndef BLE_BAS_C_ENABLED
#define BLE_BAS_C_ENABLED 0
#endif

// <q> BLE_BAS_ENABLED  - ble_bas - Battery Service


#ifndef BLE_BAS_ENABLED
#define BLE_BAS_ENABLED 0
#endif

// <q> BLE_CSCS_ENABLED  - ble_cscs - Cycling Speed and Cadence Service


#ifndef BLE_CSCS_ENABLED
#define BLE_CSCS_ENABLED 0
#endif

// <q> BLE_CTS_C_ENABLED  - ble_cts_c - Current Time Service Client


#ifndef BLE_CTS_C_ENABLED
#define BLE_CTS_C_ENABLED 0
#endif

// <q> BLE_DIS_ENABLED  - ble_dis - Device Information Service


#ifndef BLE_DIS_ENABLED
#define BLE_DIS_ENABLED 0
#endif

// <q> BLE_GLS_ENABLED  - ble_gls - Glucose Service


#ifndef BLE_GLS_ENABLED
#define BLE_GLS_ENABLED 0
#endif

// <q> BLE_HIDS_ENABLED  - ble_hids - Human Interface Device Service


#ifndef BLE_HIDS_ENABLED
#define BLE_HIDS_ENABLED 0
#endif

// <e> BLE_HRS_C_ENABLED - ble_hrs_c - Heart Rate Service Client
//==========================================================
#ifndef BLE_HRS_C_ENABLED
#define BLE_HRS_C_ENABLED 0
#endif
#if  BLE_HRS_C_ENABLED
// <o> BLE_HRS_C_RR_INTERVALS_MAX_CNT - Maximum number of RR_INTERVALS per notification to be decoded
#ifndef BLE_HRS_C_RR_INTERVALS_MAX_CNT
#define BLE_HRS_C_RR_INTERVALS_MAX_CNT 30
#endif

#endif //BLE_HRS_C_ENABLED
// </e>

// <q> BLE_HRS_ENABLED  - ble_hrs - Heart Rate Service


#ifndef BLE_HRS_ENABLED
#define BLE_HRS_ENABLED 0
#endif

// <q> BLE_HTS_ENABLED  - ble_hts - Health Thermometer Service


#ifndef BLE_HTS_ENABLED
#define BLE_HTS_ENABLED 0
#endif

// <q> BLE_IAS_C_ENABLED  - ble_ias_c - Immediate Alert Service Client


#ifndef BLE_IAS_C_ENABLED
#define BLE_IAS_C_ENABLED 0
#endif

// <q> BLE_IAS_ENABLED  - ble_ias - Immediate Alert Service


#ifndef BLE_IAS_ENABLED
#define BLE_IAS_ENABLED 0
#endif

// <q> BLE_LBS_C_ENABLED  - ble_lbs_c - Nordic LED Button Service Client


#ifndef BLE_LBS_C_ENABLED
#define BLE_LBS_C_ENABLED 0
#endif

// <q> BLE_LBS_ENABLED  - ble_lbs - LED Button Service


#ifndef BLE_LBS_ENABLED
#define BLE_LBS_ENABLED 0
#endif

// <q> BLE_LLS_ENABLED  - ble_lls - Link Loss Service


#ifndef BLE_LLS_ENABLED
#define BLE_LLS_ENABLED 0
#endif

// <q> BLE_NUS_C_ENABLED  - ble_nus_c - Nordic UART Central Service


#ifndef BLE_NUS_C_ENABLED
#define BLE_NUS_C_ENABLED 0
#endif

// <q> BLE_NUS_ENABLED  - ble_nus - Nordic UART Service


#ifndef BLE_NUS_ENABLED
#define BLE_NUS_ENABLED 1
#endif

// <q> BLE_RSCS_C_ENABLED  - ble_rscs_c - Running Speed and Cadence Client


#ifndef BLE_RSCS_C_ENABLED
#define BLE_RSCS_C_ENABLED 0
#endif

// <q> BLE_RSCS_ENABLED  - ble_rscs - Running Speed and Cadence Service


#ifndef BLE_RSCS_ENABLED
#define BLE_RSCS_ENABLED 0
#endif

// <q> BLE_TPS_ENABLED  - ble_tps - TX Power Service


#ifndef BLE_TPS_ENABLED
#define BLE_TPS_ENABLED 0
#endif

// </h>
//==========================================================

// <h> nRF_Drivers

//==========================================================
// <e> ADC_ENABLED - nrf_drv_adc - Driver for ADC peripheral (nRF51)
//==========================================================
#ifndef ADC_ENABLED
#define ADC_ENABLED 0
#endif
#if  ADC_ENABLED
// <o> ADC_CONFIG_IRQ_PRIORITY  - Interrupt priority


// <i> Priorities 0,2 (nRF51) and 0,1,4,5 (nRF52) are reserved for SoftDevice
// <0=> 0 (highest)
// <1=> 1
// <2=> 2
// <3=> 3

#ifndef ADC_CONFIG_IRQ_PRIORITY
#define ADC_CONFIG_IRQ_PRIORITY 3
#endif
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

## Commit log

2019-01-03 Initial commit
    A Bluetooth Low Energy (BLE) enabled Harry Potter Sorting Hat.
    This project replaces the original electronics in the Harry Potter
    Sorting Hat from Barnes and Noble,
    https://www.barnesandnoble.com/w/home-gift-harry-potter-sorting-hat/30008992,
    with a Nordic nRF5 BLE capable device.
    Pins.h contains the definitions for which pins are connected to which
    external hardware.
    The user can connect to the device with a BLE capable phone using the
    Nordic UART serice and send 'g', 'r', 'h', or 's' to select the house
    and then a series of random clips from the movies will play, ending
    with an announcement of the selected house.
    The sound clips are stored on SD card as .wav files and ar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
    [OneBitSound.c, Pins.h, main.c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]
2019-01-03 Generate audio files
    Added the https://github.com/gowenrw/arduino_sorting_hat repository
    from @gowenrw as a submodule. It contains the required audio clips as
    MP3 files. I added an 'audio' rule to my main makefile which is able to
    convert these to the required 22.050kHz mono .wav files required by the
    playback code that I wrote for the nRF51. The generated files should be
    placed in the root folder of the SD card.
2019-01-05 First attempt at schematic
    [SortingHat.sch]
2019-01-07 Version 1 of the PCB
    This is the design as I sent it off to OSHPark.
    [SortingHat.brd, SortingHat.sch]
2019-01-07 Fix typos
    Mostly just fixing typos I noticed in the comments. Also including a
    change to use the ARRAY_SIZE macro instead of hardcoding a size.
    [main.c]
2019-01-08 Add version 1 schematic & PCB images
2019-01-08 Update README
    Documenting BOM, schematic, and PCB renderings.
2019-01-16 Update firmware to work on custom board
    Starting bringup on the actual custom PCB. This commit includes:
    * Remove all references to the BSP (board support package) since I have
    no buttons or switches on this custom board. I do still configure
    the random selection switch as I did previously as it was already
    separate from the BSP supported switches.
    * This PCB uses different pins for things like the sound output pin,
    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
2019-01-25 Initial commit of iOS application
    This is a simple application which connects to the Sorting Hat from an
    iPhone for the purpose of selecting the house to be announced. It
    automatically reconnects after the hat finishes its announcement and
    turns the radio back on (once it no longer needs the CPU resources for
    sound playback). The user is presented with 4 buttons, one for each
    house, and will need to press the desired button twice to start the
    hat announcement so that a single incorrect button tap isn't registered
    by mistake.

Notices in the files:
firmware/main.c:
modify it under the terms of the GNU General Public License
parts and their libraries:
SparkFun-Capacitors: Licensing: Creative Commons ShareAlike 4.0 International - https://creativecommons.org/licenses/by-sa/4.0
